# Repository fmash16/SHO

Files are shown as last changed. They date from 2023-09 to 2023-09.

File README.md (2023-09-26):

# The SHO (ষ)

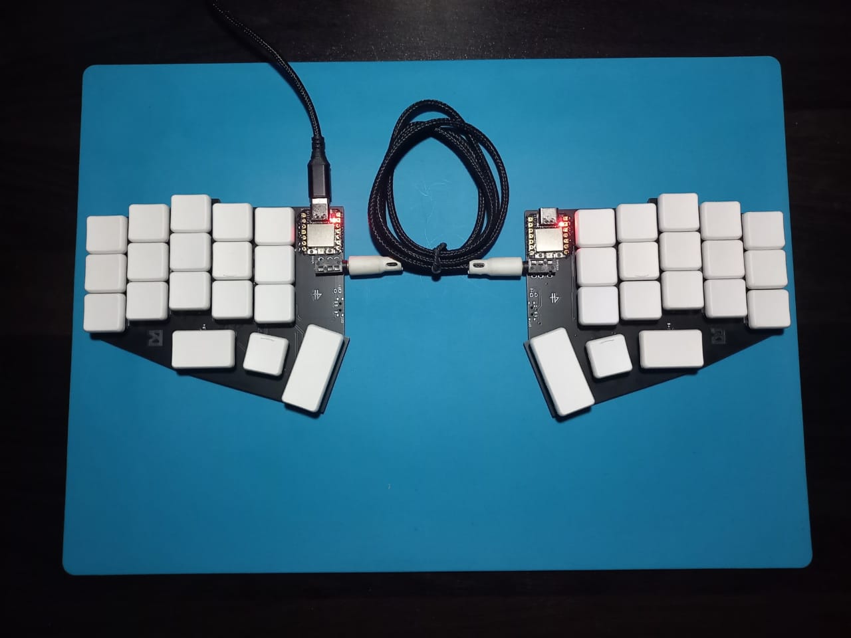
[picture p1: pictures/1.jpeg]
SHO

The ষ (SHO) is a 36 key choc spaced split keyboard based on the Seeduino XIAO controller. For the design, I took huge inspiration from the gergoplex which I love the look of. This keyboard uses the Seeduino Seed RP2040 as the MCU, which is really great for the price and the small size. Just love how compact it turned out coming from MX boards.

## Features:

1. XIAO RP 2040 / BLE controller for wired/wireless versions
2. Reversible PCBs
3. Soldered on Kailh Choc V1 switches (Choc whites in my build)
4. TRS/TRRS connection between both halves

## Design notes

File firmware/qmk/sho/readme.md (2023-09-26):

#SHO 

sho

Low-profile split keyboard with 36 keys using XIAO controllers.

-   Keyboard Maintainer: [fmash16](https://github.com/fmash16)
-   Hardware Supported: sho PCBs, XIAO RP2040/nRF52840
-   Hardware Availability: [GitHub](https://github.com/fmash16/sho)

Make example for this keyboard (after setting up your build environment):

    make sho:default

Flashing example for this keyboard:

    make sho:default:flash

See the [build environment setup](https://docs.qmk.fm/#/getting_started_build_tools) and the [make instructions](https://docs.qmk.fm/#/getting_started_make_guide) for more information. Brand new to QMK? Start with our [Complete Newbs Guide](https://docs.qmk.fm/#/newbs).

## Bootloader

Enter the bootloader in 3 ways:

-   **Bootmagic reset**: Hold down the key at (0,0) in the matrix (usually the top left key or Escape) and plug in the keyboard
-   **Physical reset button**: Briefly press the button on the back of the PCB - some may have pads you must short instead
-   **Keycode in layout**: Press the key mapped to `RESET` if it is available

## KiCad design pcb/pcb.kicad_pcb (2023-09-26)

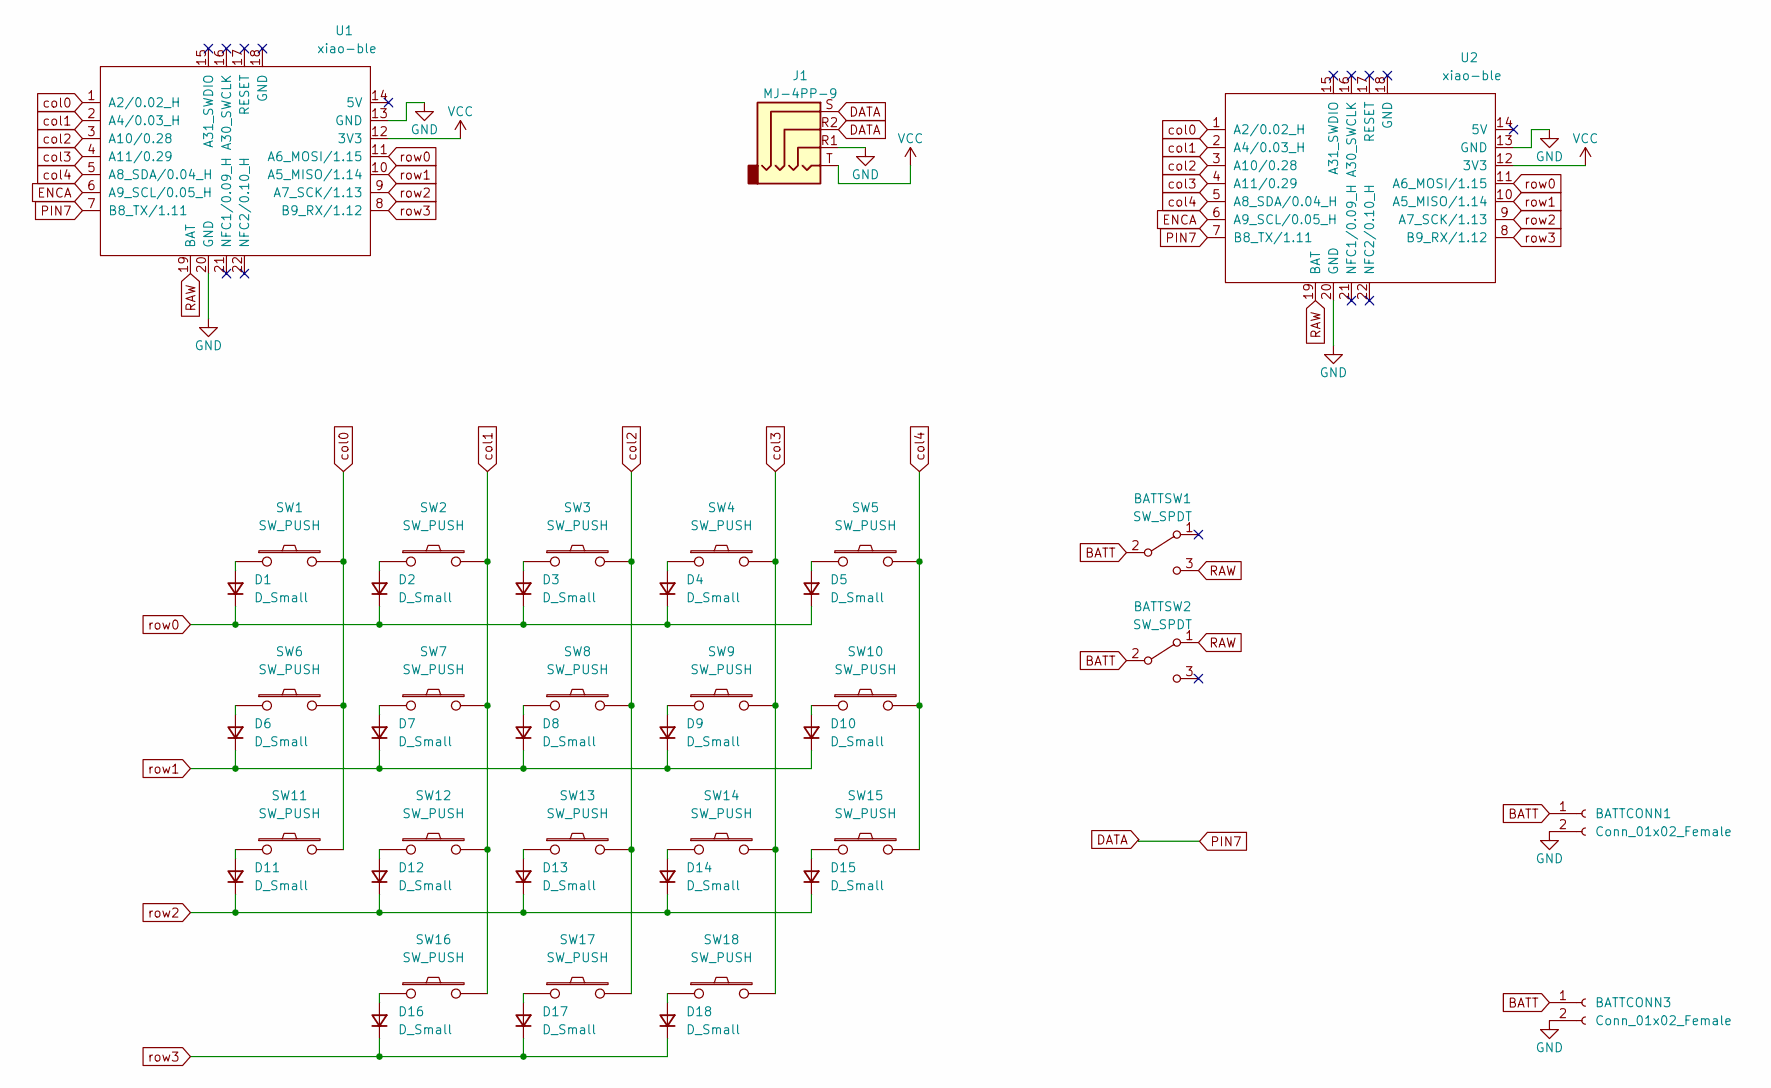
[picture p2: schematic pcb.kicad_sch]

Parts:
BATTCONN1, BATTCONN3: Conn_01x02_Female; Connector_JST-1x02-2.00mm
BATTSW1, BATTSW2: SW_SPDT; Switch_SPDT-PCM12
D1, D2, D3, D4, D5, D6, D7, D8, D9, D10, D11, D12, D13, D14, D15, D16, D17, D18: D_Small; Diode_1N4148-SOD123-reversible
J1: MJ-4PP-9; Connector_TRRS-reversible
SW1, SW2, SW3, SW4, SW5, SW6, SW7, SW8, SW9, SW10, SW11, SW12, SW13, SW14, SW15, SW16, SW17, SW18: SW_PUSH; Switch_ChocV1-reversible
U1, U2: xiao-ble; MCU_xiao-ble-smd

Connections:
BATT: BATTCONN1.1, BATTCONN3.1, BATTSW1.2 (B), BATTSW2.2 (B)
DATA: J1.R2, J1.S, U1.7 (B8_TX/1.11), U2.7 (B8_TX/1.11)
ENCA: U1.6 (A9_SCL/0.05_H), U2.6 (A9_SCL/0.05_H)
GND: BATTCONN1.2, BATTCONN3.2, J1.R1, U1.13 (GND), U1.20 (GND), U2.13 (GND), U2.20 (GND)
unnamed: D1.2 (A), SW1.1
unnamed: D2.2 (A), SW2.1
unnamed: D3.2 (A), SW3.1
unnamed: D4.2 (A), SW4.1
unnamed: D5.2 (A), SW5.1
unnamed: D6.2 (A), SW6.1
unnamed: D7.2 (A), SW7.1
unnamed: D8.2 (A), SW8.1
unnamed: D9.2 (A), SW9.1
unnamed: D10.2 (A), SW10.1
unnamed: D11.2 (A), SW11.1
unnamed: D12.2 (A), SW12.1
unnamed: D13.2 (A), SW13.1
unnamed: D14.2 (A), SW14.1
unnamed: D15.2 (A), SW15.1
unnamed: D16.2 (A), SW16.1
unnamed: D17.2 (A), SW17.1
unnamed: D18.2 (A), SW18.1
RAW: BATTSW1.3 (C), BATTSW2.1 (A), U1.19 (BAT), U2.19 (BAT)
VCC: J1.T, U1.12 (3V3), U2.12 (3V3)
col0: SW1.2, SW6.2, SW11.2, U1.1 (A2/0.02_H), U2.1 (A2/0.02_H)
col1: SW2.2, SW7.2, SW12.2, SW16.2, U1.2 (A4/0.03_H), U2.2 (A4/0.03_H)
col2: SW3.2, SW8.2, SW13.2, SW17.2, U1.3 (A10/0.28), U2.3 (A10/0.28)
col3: SW4.2, SW9.2, SW14.2, SW18.2, U1.4 (A11/0.29), U2.4 (A11/0.29)
col4: SW5.2, SW10.2, SW15.2, U1.5 (A8_SDA/0.04_H), U2.5 (A8_SDA/0.04_H)
row0: D1.1 (K), D2.1 (K), D3.1 (K), D4.1 (K), D5.1 (K), U1.11 (A6_MOSI/1.15), U2.11 (A6_MOSI/1.15)
row1: D6.1 (K), D7.1 (K), D8.1 (K), D9.1 (K), D10.1 (K), U1.10 (A5_MISO/1.14), U2.10 (A5_MISO/1.14)
row2: D11.1 (K), D12.1 (K), D13.1 (K), D14.1 (K), D15.1 (K), U1.9 (A7_SCK/1.13), U2.9 (A7_SCK/1.13)
row3: D16.1 (K), D17.1 (K), D18.1 (K), U1.8 (B9_RX/1.12), U2.8 (B9_RX/1.12)

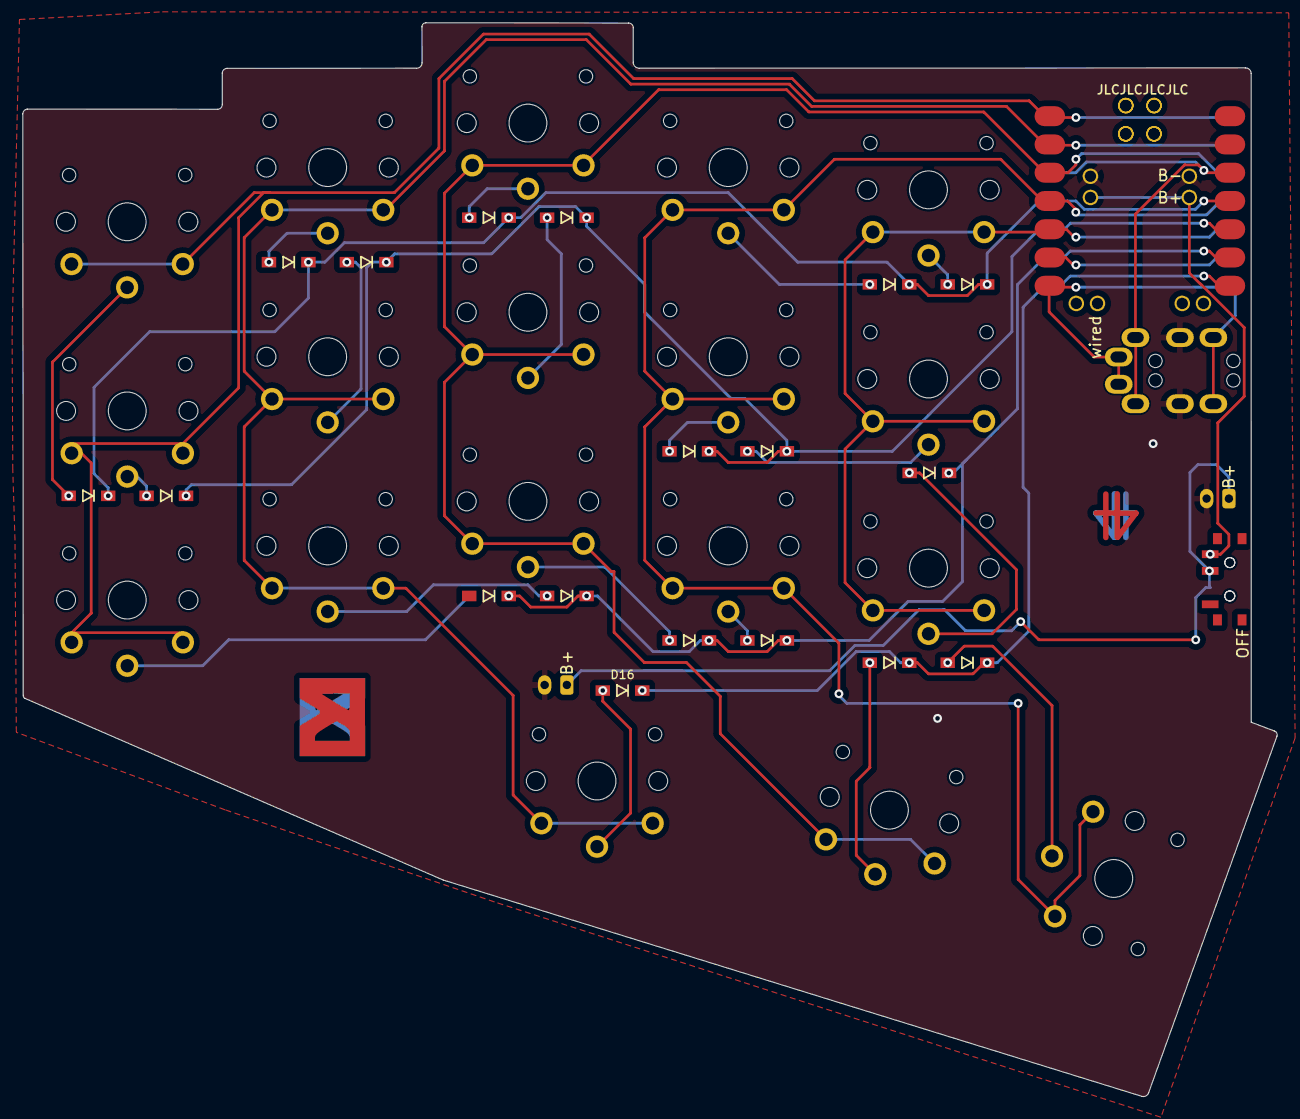
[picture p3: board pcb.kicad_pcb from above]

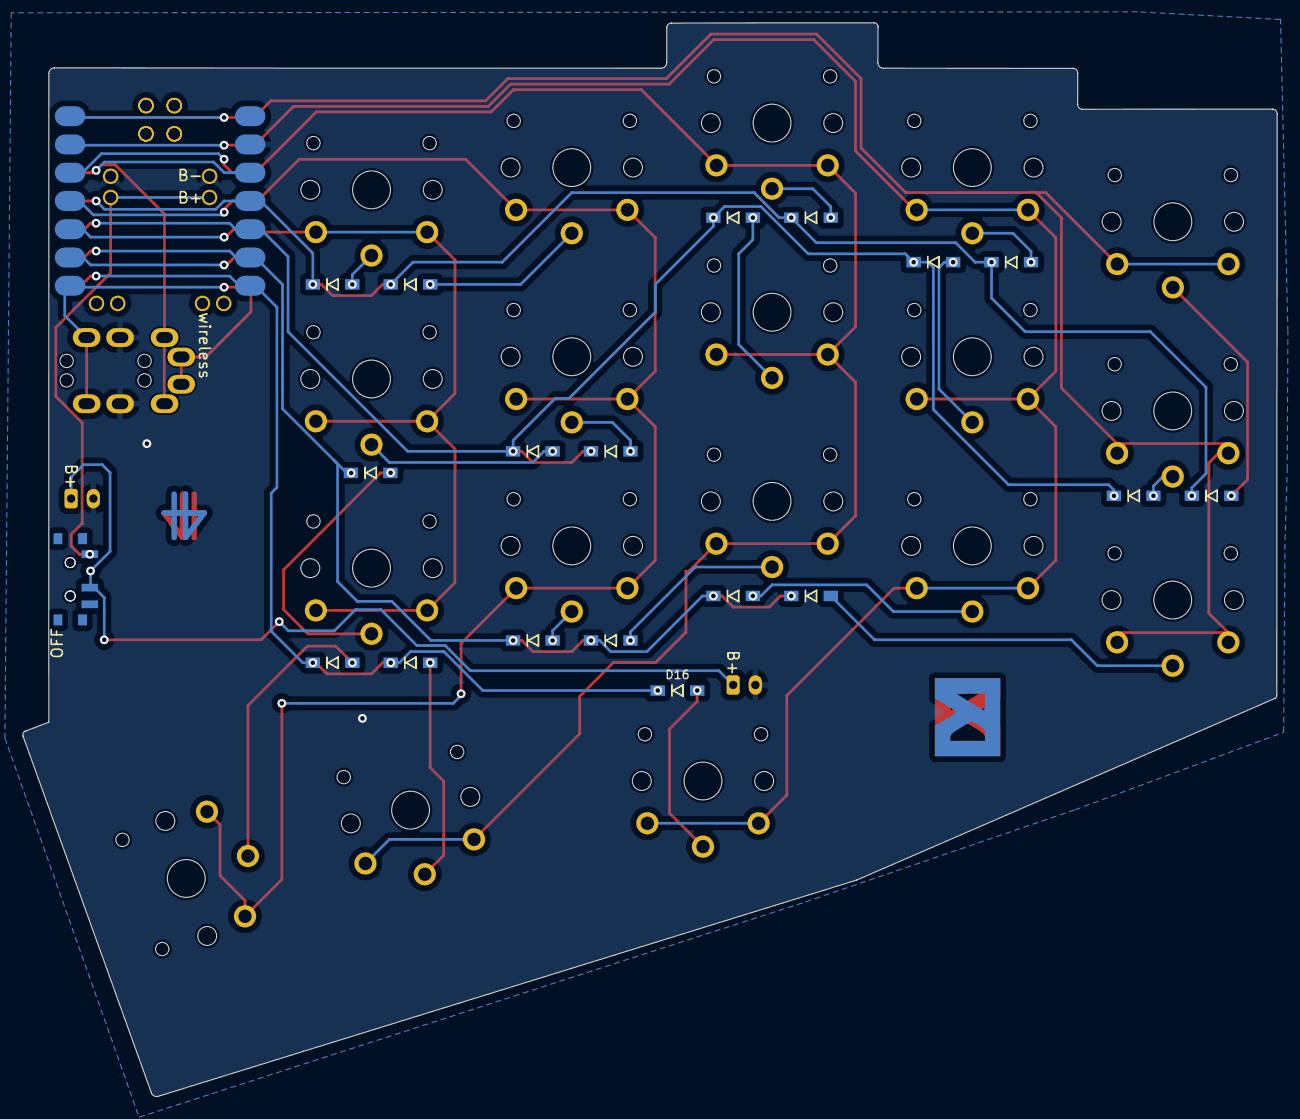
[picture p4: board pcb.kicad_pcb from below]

Board: 2 copper layers, 112.7 x 96.5 mm, 43 parts (2 on the bottom side), 33 nets.
